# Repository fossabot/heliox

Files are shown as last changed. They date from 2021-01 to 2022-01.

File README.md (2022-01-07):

# Heliox





FOSSA Status (https://app.fossa.com/projects/git%2Bgithub.com%2FGHOSCHT%2Fheliox?ref=badge_shield)
<a href="https://www.figma.com/file/fK5tEIw4Zx8AivuVbu79Lw/Light-Control">
  
</a>

Uses: https://github.com/GHOSCHT/simple-electron-react-boilerplate

Dashboard: node-gyp fails on sqlite3 build -> set default pyhton version to python 2
```
node-gyp --python /path/to/python2.7/python.exe
```
or
```
npm config set python /path/to/executable/python2.7
```   

## License
FOSSA Status (https://app.fossa.com/projects/git%2Bgithub.com%2FGHOSCHT%2Fheliox?ref=badge_large)

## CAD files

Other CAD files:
Devices/Module/Hardware/Enclosure/Back Cover v18.f3z
Devices/Module/Hardware/Enclosure/Front Cover v3.f3d

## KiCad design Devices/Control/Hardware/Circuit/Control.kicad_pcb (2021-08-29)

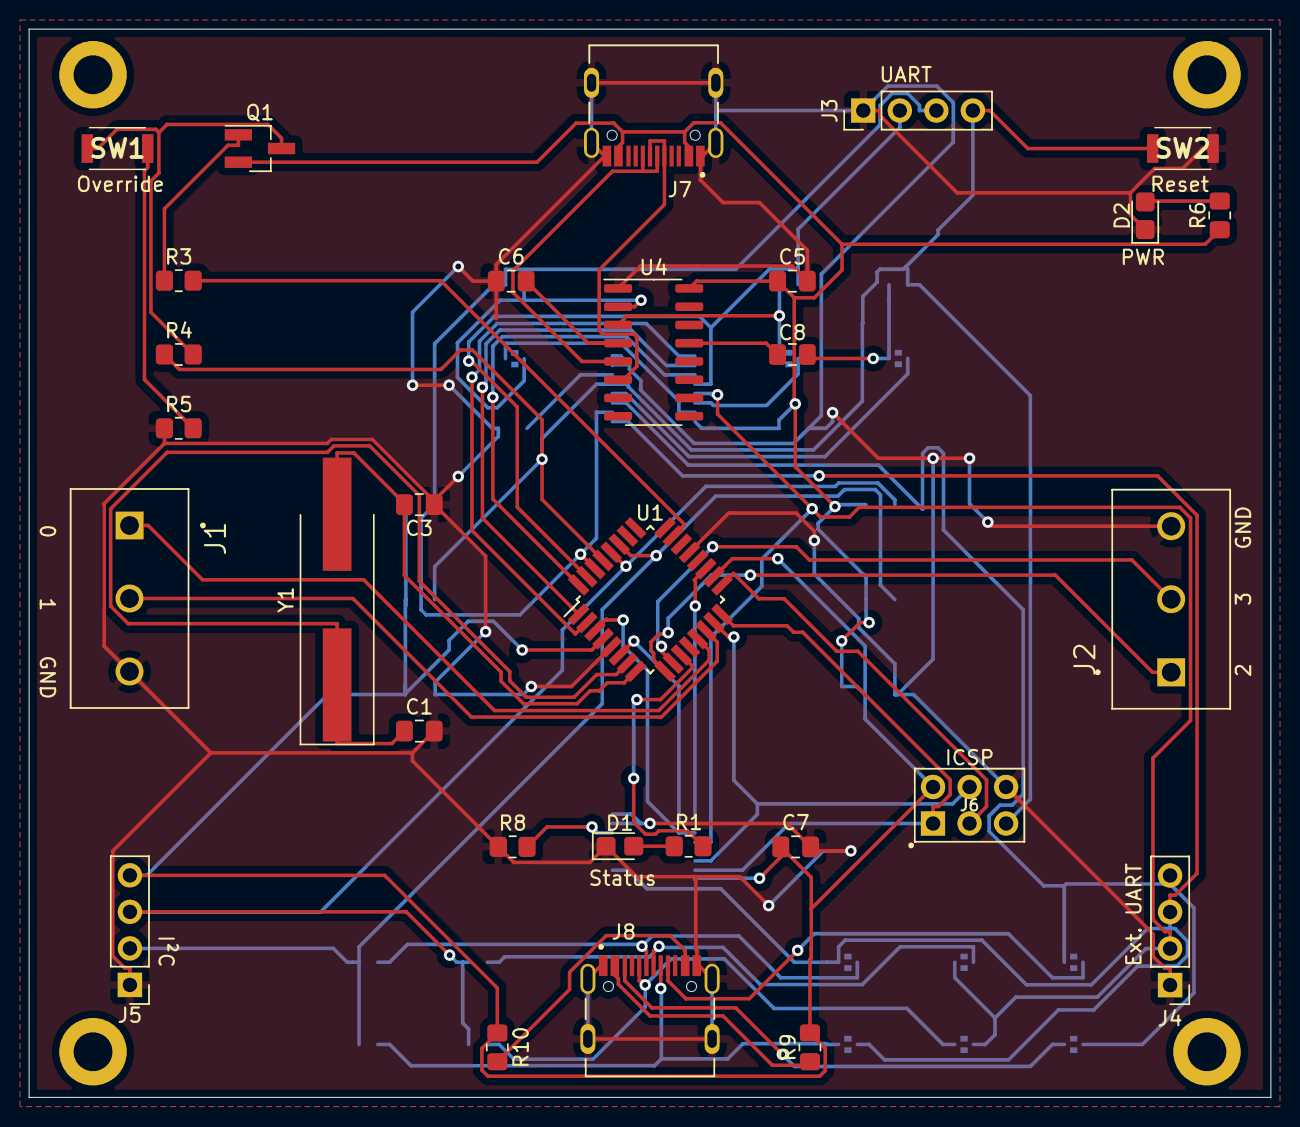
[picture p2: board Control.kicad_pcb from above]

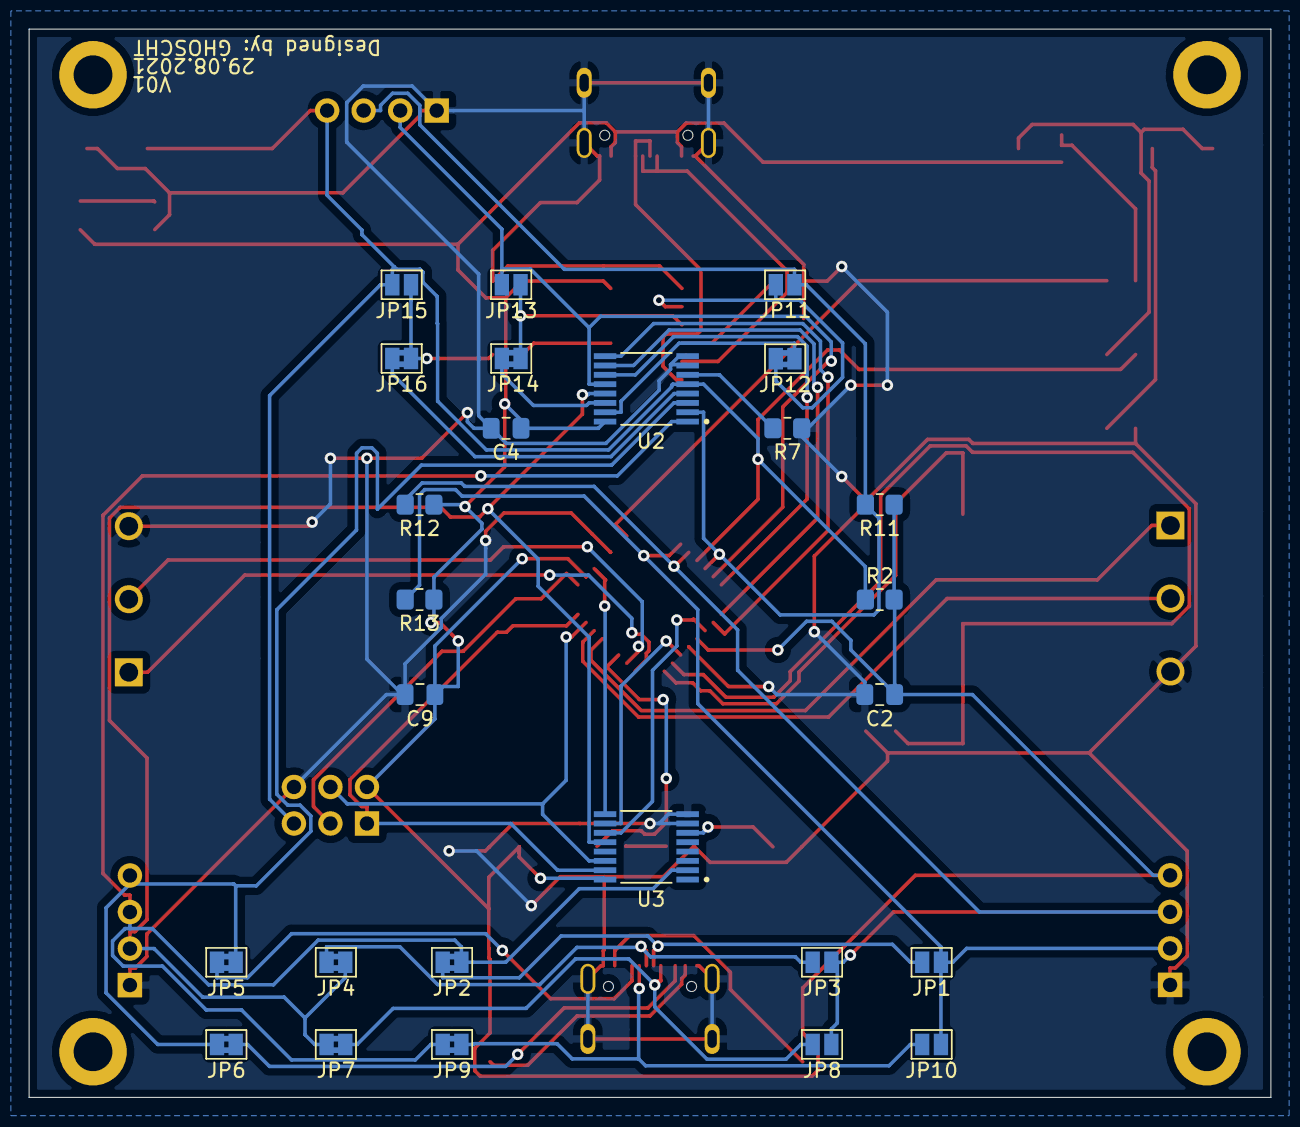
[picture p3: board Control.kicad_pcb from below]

Board: 2 copper layers, 86.4 x 74.3 mm, 60 parts (26 on the bottom side), 52 nets.

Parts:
C1, C3: 22p; C_0805_2012Metric_Pad1.18x1.45mm_HandSolder
C2, C4, C5, C6, C7, C8, C9: 100n; C_0805_2012Metric_Pad1.18x1.45mm_HandSolder
D1, D2: 17-21/BHC-XL2M2TY/3T; LED_0805_2012Metric_Castellated
J1, J2: Screw_Terminal_01x03; CUI_TB006-508-03BE
J3, J4, J5: Conn_01x04; PinHeader_1x04_P2.54mm_Vertical
J6: AVR-ISP-6; AVR-ISP
J7, J8: TYPE-C-31-M-12; HRO_TYPE-C-31-M-12
JP1, JP3, JP8, JP10, JP11, JP13, JP15: SolderJumper; SolderJumper-2_P1.3mm_Open_Pad1.0x1.5mm
JP2, JP4, JP5, JP6, JP7, JP9, JP12, JP14, JP16: SolderJumper_Bridged; SolderJumper-2_P1.3mm_Bridged2Bar_Pad1.0x1.5mm
MNT1, MNT2, MNT3, MNT4: MountingHole_2.7mm_M2.5_DIN965_Pad
Q1: Q_NPN_BCE; SOT-23_Handsoldering
R1, R6: 200; R_0805_2012Metric_Pad1.20x1.40mm_HandSolder
R2, R7, R8, R11, R12, R13: 10k; R_0805_2012Metric_Pad1.20x1.40mm_HandSolder
R3, R5, R9, R10: 40.2; R_0805_2012Metric_Pad1.20x1.40mm_HandSolder
R4: 120; R_0805_2012Metric_Pad1.20x1.40mm_HandSolder
SW1, SW2: SW_Push; SKRKAEE020
U1: ATmega328PB-AU; TQFP-32_7x7mm_P0.8mm
U2, U3: CD74HC4053PWR; SOP65P640X120-16N
U4: CH340C; SOIC-16_3.9x9.9mm_P1.27mm
Y1: 16MHz; Crystal_SMD_HC49-SD_HandSoldering

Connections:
D+: J7.A6, J7.B6, U4.5
D-: J7.A7, J7.B7, U4.6
EXTRST: J4.4, JP5.1, JP6.2, U2.3
EXTRX: J4.3, JP2.1, JP9.2, U2.1, U3.2
EXTTX: J4.2, JP4.1, JP7.2, U2.13, U3.12
GND: C1.2, C2.2, C3.2, C4.2, C5.2, C6.1, C7.2, C9.2, D1.1, D2.1, J1.3, J2.3, J3.1, J4.1, J5.1, J6.6, J7.A1B12, J7.B1A12, J7.S1, J7.S2, J7.S3, J7.S4, J8.A1B12, J8.B1A12, J8.S1, J8.S2, J8.S3, J8.S4, R5.1, R7.1, R8.1, SW2.2, U1.5, U1.21, U2.7, U2.8, U3.7, U3.8, U4.1
LED: R1.2, U1.11
MISO: J6.1, U1.16, U3.15
MOSI: J6.4, U1.15, U3.14
MUX1S0: U1.32, U2.11
MUX1S1: U1.1, U2.10
MUX1S2: U1.2, U2.9
MUX2S0: U1.3, U3.11
MUX2S1: U1.6, U3.10
MUX2S2: U1.19, U3.9
MUXRST: JP16.1, U2.4
MUXRX: JP12.1, U2.15
MUXTX: JP14.1, U2.14
unnamed: C6.2, U4.4
unnamed: C8.1, JP15.1, JP16.2
unnamed: C8.2, U4.13
unnamed: D1.2, R1.1
unnamed: D2.2, R6.1
unnamed: J8.A4B9, R9.2
unnamed: J8.A6, JP1.2, JP2.2
unnamed: J8.A7, JP3.2, JP4.2
unnamed: J8.A8, JP5.2
unnamed: J8.B4A9, R10.2
unnamed: J8.B6, JP9.1, JP10.2
unnamed: J8.B7, JP7.1, JP8.2
unnamed: J8.B8, JP6.1
unnamed: JP11.1, JP12.2, U4.2
unnamed: JP13.1, JP14.2, U4.3
unnamed: Q1.1, R3.1
unnamed: Q1.3, R4.2, SW1.1
unnamed: R5.2, SW1.2
unnamed: R7.2, U2.6
unnamed: R8.2, U3.6
RST: J3.4, J6.5, JP15.2, R2.1, R4.1, SW2.1, U1.29, U2.5
RX: J3.3, JP11.2, R11.2, U1.30, U2.2
SCK: J6.3, U1.17
SCL: J5.3, JP3.1, JP8.1, R12.2, U1.28
SDA: J5.2, JP1.1, JP10.1, R13.2, U1.27
SIG1A: J1.1, U1.13
SIG1B: J1.2, U1.14
SIG2A: J2.1, U1.9
SIG2B: J2.2, U1.10
STOPRST: R3.2, U1.23
TX: J3.2, JP13.2, U1.31, U2.12
VCC: C2.1, C4.1, C5.1, C7.1, C9.1, J5.4, J6.2, J7.A4B9, J7.B4A9, Q1.2, R2.2, R6.2, R9.1, R10.1, R11.1, R12.1, R13.1, U1.4, U1.18, U2.16, U3.16, U4.16
XTAL1: C1.1, U1.7, Y1.1
XTAL2: C3.1, U1.8, Y1.2

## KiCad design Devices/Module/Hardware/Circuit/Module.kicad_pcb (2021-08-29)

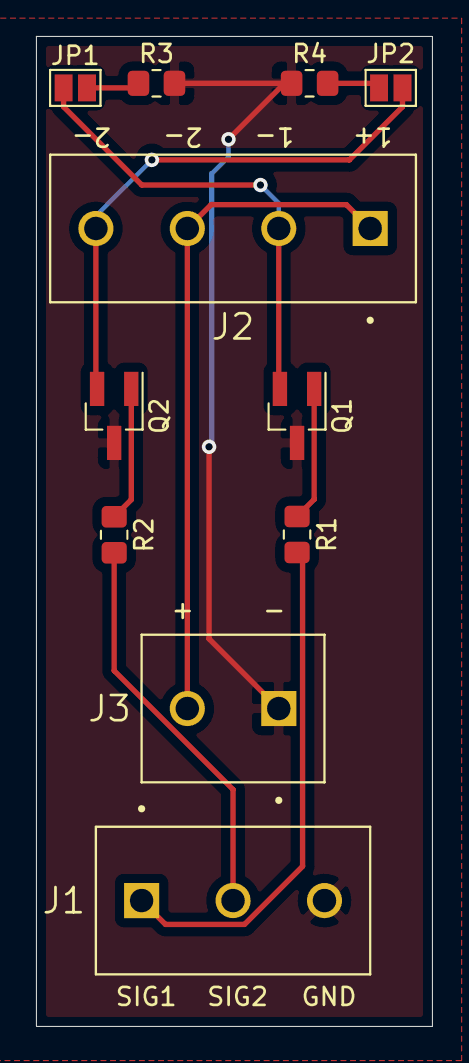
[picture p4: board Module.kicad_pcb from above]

Board: 2 copper layers, 22.0 x 55.0 mm, 11 parts (0 on the bottom side), 10 nets.

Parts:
J1: Screw_Terminal_01x03; CUI_TB006-508-03BE
J2: Screw_Terminal_01x04; CUI_TB006-508-04BE
J3: Screw_Terminal_01x02; CUI_TB006-508-02BE
JP1, JP2: Jumper; SolderJumper-2_P1.3mm_Open_Pad1.0x1.5mm
Q1, Q2: Q_NPN_BCE; SOT-23_Handsoldering
R1, R2: 470; R_0805_2012Metric_Pad1.20x1.40mm_HandSolder
R3, R4: 10k; R_0805_2012Metric_Pad1.20x1.40mm_HandSolder

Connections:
GND: J1.3, J3.1, Q1.3, Q2.3, R3.2, R4.1
LED1N: J2.2, JP1.1, Q1.2
LED2N: J2.4, JP2.1, Q2.2
unnamed: JP1.2, R3.1
unnamed: JP2.2, R4.2
unnamed: Q1.1, R1.1
unnamed: Q2.1, R2.1
SIG1: J1.1, R1.2
SIG2: J1.2, R2.2
VCC: J2.1, J2.3, J3.2

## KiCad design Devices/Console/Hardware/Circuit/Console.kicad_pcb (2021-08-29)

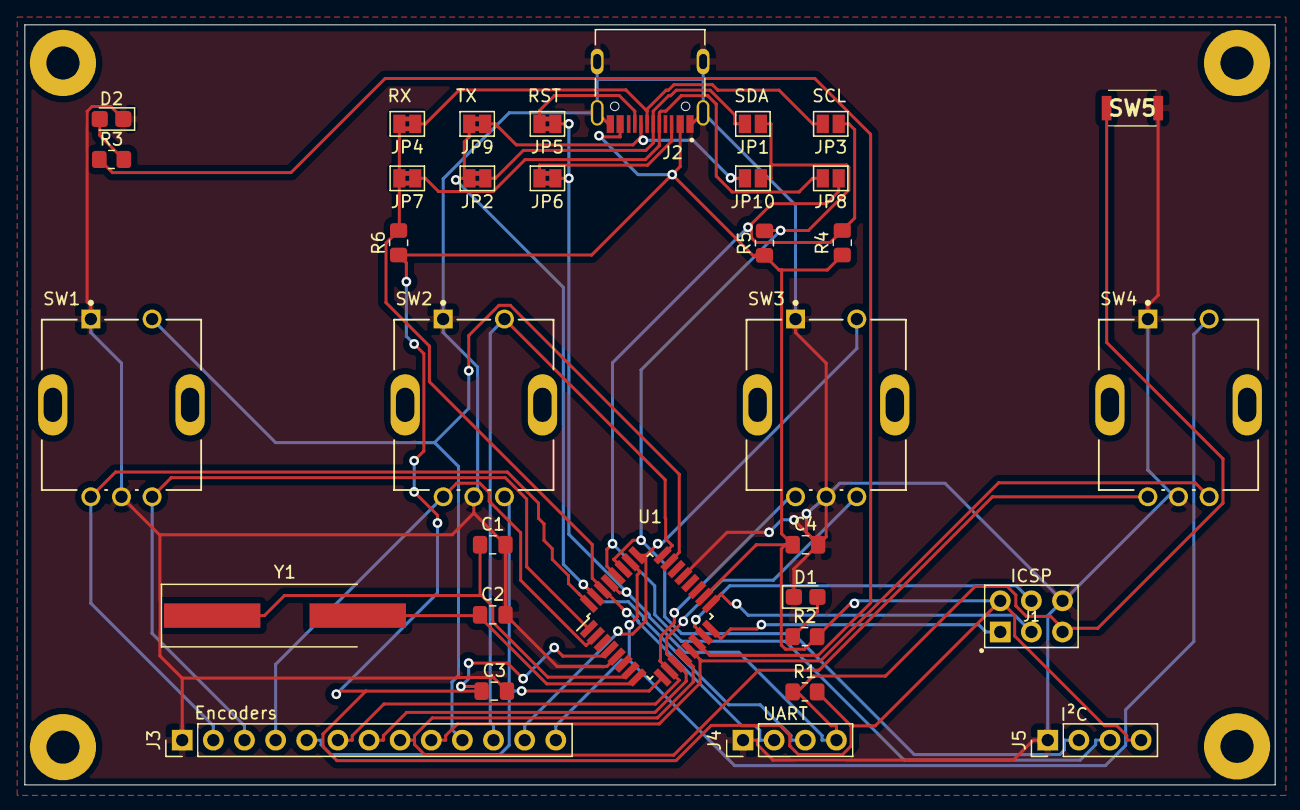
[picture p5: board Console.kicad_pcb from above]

Board: 2 copper layers, 102.0 x 62.0 mm, 38 parts (0 on the bottom side), 33 nets.

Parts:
C1, C2: 22p; C_0805_2012Metric_Pad1.18x1.45mm_HandSolder
C3, C4: 100n; C_0805_2012Metric_Pad1.18x1.45mm_HandSolder
D1, D2: 17-21/BHC-XL2M2TY/3T; LED_0805_2012Metric_Castellated
J1: AVR-ISP-6; AVR-ISP
J2: TYPE-C-31-M-12; HRO_TYPE-C-31-M-12
J3: Conn_01x13; PinHeader_1x13_P2.54mm_Vertical
J4, J5: Conn_01x04; PinHeader_1x04_P2.54mm_Vertical
JP1, JP3, JP8, JP10: SolderJumper; SolderJumper-2_P1.3mm_Open_Pad1.0x1.5mm
JP2, JP4, JP5, JP6, JP7, JP9: SolderJumper_Bridged; SolderJumper-2_P1.3mm_Bridged2Bar_Pad1.0x1.5mm
PAD1, PAD2, PAD3, PAD4: MountingHole_2.7mm_M2.5_Pad
R1, R4, R5, R6: 10k; R_0805_2012Metric_Pad1.20x1.40mm_HandSolder
R2, R3: 200; R_0805_2012Metric_Pad1.20x1.40mm_HandSolder
SW1, SW2, SW3, SW4: PEC11R-4220F-S0012; Bourns-PEC11R-4220F-S0012-MFG
SW5: SW_Push; SKRKAEE020
U1: ATmega328PB-AU; TQFP-32_7x7mm_P0.8mm
Y1: 16MHz; Crystal_SMD_HC49-SD_HandSoldering

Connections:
BTN1: J3.10, SW1.S2, U1.23
BTN2: J3.11, SW2.S2, U1.24
BTN3: J3.12, SW3.S2, U1.25
BTN4: J3.13, SW4.S2, U1.26
ENC1A: J3.2, SW1.A, U1.32
ENC1B: J3.3, SW1.B, U1.1
ENC2A: J3.4, SW2.A, U1.2
ENC2B: J3.5, SW2.B, U1.9
ENC3A: J3.6, SW3.A, U1.10
ENC3B: J3.7, SW3.B, U1.11
ENC4A: J3.8, SW4.A, U1.12
ENC4B: J3.9, SW4.B, U1.13
GND: C1.2, C2.2, C3.2, C4.2, D1.1, D2.1, J1.6, J2.A1B12, J2.B1A12, J2.S1, J2.S2, J2.S3, J2.S4, J3.1, J4.1, J5.1, SW1.C, SW1.S1, SW2.C, SW2.S1, SW3.C, SW3.S1, SW4.C, SW4.S1, SW5.2, U1.5, U1.21
LED: R3.2, U1.14
MISO: J1.1, U1.16
MOSI: J1.4, U1.15
unnamed: D1.2, R2.1
unnamed: D2.2, R3.1
unnamed: J2.A6, JP1.2, JP2.2
unnamed: J2.A7, JP3.2, JP4.2
unnamed: J2.A8, JP5.2
unnamed: J2.B6, JP9.1, JP10.1
unnamed: J2.B7, JP7.1, JP8.1
unnamed: J2.B8, JP6.1
RST: J1.5, J4.4, JP5.1, JP6.2, R1.1, SW5.1, U1.29
RX: J4.2, JP4.1, JP7.2, R6.2, U1.30
SCK: J1.3, U1.17
SCL: J5.3, JP3.1, JP8.2, R4.2, U1.28
SDA: J5.2, JP1.1, JP10.2, R5.2, U1.27
TX: J4.3, JP2.1, JP9.2, U1.31
VCC: C3.1, C4.1, J1.2, J2.A4B9, J2.B4A9, J5.4, R1.2, R2.2, R4.1, R5.1, R6.1, U1.4, U1.18
XTAL1: C1.1, U1.7, Y1.1
XTAL2: C2.1, U1.8, Y1.2

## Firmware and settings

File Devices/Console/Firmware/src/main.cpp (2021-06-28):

#include <Arduino.h>
#include <Wire.h>

//General
const int bjtCount = 4;
const int btnPin[bjtCount] = {7, 8, 9, 10};

byte btnState[bjtCount];
byte lastBtnState[bjtCount] = {HIGH, HIGH, HIGH, HIGH};

unsigned long lastDebounceTime[bjtCount] = {0, 0, 0, 0};
unsigned long debounceDelay = 50;

//I2C
const int SLAVE_ADDR = 9;

//Rotary Encoder
const int encClkPin[1] = {6};
const int encDtPin[1] = {5};

void setup()
{
    Serial.begin(9600);
    Wire.begin();

    for (int i = 0; i < bjtCount; i++)
    {
        pinMode(btnPin[i], INPUT_PULLUP);
        pinMode(encClkPin[i], INPUT_PULLUP);
        pinMode(encDtPin[i], INPUT_PULLUP);
    }
}

void transmit(String data)
{
    Wire.beginTransmission(SLAVE_ADDR);
    Wire.write(data.c_str(), 2);
    Serial.println(data.c_str());
    Wire.endTransmission();
}

void loop()
{
    //Buttons
    byte btnReading[bjtCount];

    for (int i = 0; i < bjtCount; i++)
    {
        btnReading[i] = digitalRead(btnPin[i]);

        if (btnReading[i] != lastBtnState[i])
        {
            lastDebounceTime[i] = millis();
        }

        if ((millis() - lastDebounceTime[i]) > debounceDelay)
        {
            if (btnReading[i] != btnState[i])
            {
                btnState[i] = btnReading[i];

                if (btnState[i] == LOW)
                {
                    transmit(String(i) + "t");
                }
            }
        }

        lastBtnState[i] = btnReading[i];
    }

    //Rotary Encoder
    static uint16_t state[1] = {0};

    //delayMicroseconds(100); // Simulate doing somehing else as well.

    for (int i = 0; i < 1; i++)
    {
        state[i] = (state[i] << 1) | digitalRead(encClkPin[i]) | 0xe000;

        if (state[i] == 0xf000)
        {
            state[i] = 0x0000;
            if (digitalRead(encDtPin[i]))
                //transmit(String(i) + "i");
                transmit("2i");
            else
                //transmit(String(i) + "d");
                transmit("2d");
        }
    }
}

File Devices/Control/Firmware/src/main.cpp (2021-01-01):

#include <Arduino.h>
#include <EEPROM.h>
#include <Wire.h>

#define SLAVE_ADDR 9
const int bjtCount = 4;

const int bjtPin[bjtCount] = {6, 5, 3, 10};
int bjtState[bjtCount] = {255, 255, 255, 255}; //255 -> bjt max "open"

char receivedSerialData[4];
char receivedI2cData[4];
String pendingSerialData;

void changeLights(char data[])
{
  for (int i = 0; i < bjtCount; i++)
  {
    char numChar[2];
    itoa(i, numChar, 10);

    if (data[0] == numChar[0])
    {
      if (data[1] == 't')
      {
        if (bjtState[i] != 0)
        {
          bjtState[i] = 0;
        }
        else
        {
          bjtState[i] = 255;
        }
      }
      else if (data[1] == 'i')
      {
        bjtState[i] += 5;
      }
      else if (data[1] == 'd')
      {
        bjtState[i] -= 5;
      }
    }

    //clamp state between 0 and 255
    if (bjtState[i] > 255)
    {
      bjtState[i] = 255;
    }

    if (bjtState[i] < 0)
    {
      bjtState[i] = 0;
    }

    //set absolute state for all
    if (!strcmp(data, "off"))
    {
      bjtState[i] = 0;
    }

    if (!strcmp(data, "on"))
    {
      bjtState[i] = 255;
    }

    analogWrite(bjtPin[i], bjtState[i]);
    EEPROM.update(i, bjtState[i]);
  }

  memset(data, ' ', 3);
}

void receiveEvent(int byteCount)
{
  char buffer[byteCount];
  for (int i = 0; i < byteCount; i++)
  {
    buffer[i] = Wire.read();
  }
  memset(receivedI2cData, ' ', 3);
  strcpy(receivedI2cData, buffer);
}

void setup()
{
  Serial.begin(9600);
  Serial.setTimeout(5);
  Wire.begin(SLAVE_ADDR);
  Wire.onReceive(receiveEvent);

  for (int i = 0; i < bjtCount; i++)
  {
    pinMode(bjtPin[i], OUTPUT);
    bjtState[i] = EEPROM.read(i);
    analogWrite(bjtPin[i], bjtState[i]);
  }
}

void loop()
{
  while (Serial.available())
  {
    strcpy(receivedSerialData, Serial.readString().c_str());
  }

  changeLights(receivedSerialData);
  changeLights(receivedI2cData);

  pendingSerialData = "";
  for (int i = 0; i < bjtCount; i++)
  {
    noInterrupts();
    pendingSerialData += String(bjtState[i]) + ",";
    interrupts();
  }
  pendingSerialData.remove(pendingSerialData.length() - 1);
  Serial.println(pendingSerialData);
}

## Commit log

2020-07-30 Switch electron boilerplates
2020-07-30 Add on & off commands + Relay state communication
2020-08-01 Add material ui
2020-08-01 Add Buttons
2020-08-01 Remove unnecessary props
2020-08-02 Arduino builder error test
2020-08-02 Revert "Arduino builder error test"
    This reverts commit 97cf7e37e65544a997c7bfe0c96db386e0ee02a5.
2020-12-18 Switch to PWM instead of Digital bjt control
2020-12-19 Implement PWM dimming via COM
2020-12-27 Implemented button sending over i2c
2020-12-27 kind of responds to i2c button press
2021-01-01 Add one rotary encoder
2021-03-27 Add Button Debouncing
2021-06-28 Add support for multiple encoders
2021-06-30 Add precommit lint-staged
2021-08-05 File restructuring
    [Console.kicad_pcb, Console.sch, Control.kicad_pcb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]
2021-08-10 Add KiCad gitignore
2021-08-10 Rough console part selection
    [Console.kicad_pcb, Console.sch]
2021-08-10 Exchange Micro USB with Type C
    [Console.kicad_pcb, Console.sch]
2021-08-10 First rough console schematic
    [Console.kicad_pcb, Console.sch]
2021-08-10 Add encoder breakout connector
    [Console.sch]
2021-08-10 Add communication breakout pins
    [Console.kicad_pcb, Console.sch]
2021-08-10 Add schematic annotations
    [Console.sch]
2021-08-11 Add led power indicator
    [Console.sch]
2021-08-11 Change net label type to global
    [Console.kicad_pcb, Console.sch]
2021-08-11 Add ERC power flag
    [Console.sch]
2021-08-13 Add basic component selection to control
    [Control.kicad_pcb, Control.sch]
2021-08-13 Make serial solder jumper bridged
    [Console.sch]
2021-08-13 Add first USB to serial functionality
    [Control.sch]
2021-08-15 Add uart multiplexer
    [Control.kicad_pcb, Control.sch]
2021-08-15 Add console UART muxing
    [Control.kicad_pcb, Control.sch]
2021-08-15 Add control reset functionality
    [Control.kicad_pcb, Control.sch]
2021-08-15 Add reset button to console
    [Console.sch]
2021-08-15 Change console reset button symbol + solder jumper footprint
    [Console.kicad_pcb, Console.sch]
2021-08-15 Add external reset sensing to control
    [Control.sch]
2021-08-16 Add Hardware Serial connections
    [Control.sch]
2021-08-16 Add first rough connections of atmega328pb
    [Control.sch]
2021-08-17 Restructure control schematic
    [Control.kicad_pcb, Control.sch]
2021-08-17 Add status led to control
    [Control.kicad_pcb, Control.sch]
2021-08-17 Add PB processor & status led to console
    [Console.kicad_pcb, Console.sch]
2021-08-17 Add module circuit files
    [Module.kicad_pcb, Module.sch]
2021-08-17 Add module enclosure files
    [Back Cover v18.f3z, Front Cover v3.f3d]
2021-08-17 Add 1x06 screw terminal files to control
2021-08-17 Add module circuit
    [Module.kicad_pcb, Module.sch]
2021-08-19 Add input serial mux & Change pin header footprint
    [Control.kicad_pcb, Control.sch]
2021-08-19 Change pin header size
    [Console.kicad_pcb, Console.sch]
2021-08-19 Change through-hole size
    [Control.kicad_pcb]
2021-08-19 Finish module PCB layout
    [Module.kicad_pcb, Module.sch]
2021-08-19 First console PCB layout
    [Console.kicad_pcb]
2021-08-19 Change ISP footprint to through-hole
    [Console.kicad_pcb]
2021-08-19 Relocate ISP header
    [Console.kicad_pcb]
2021-08-19 Flip components for easier wiring
    [Console.kicad_pcb]
2021-08-19 Add second more centered pcb layout
    [Console-v1.kicad_pcb]
2021-08-19 Finalize PCB
    [Console.kicad_pcb]
2021-08-19 Add breakout pin description
    [Console.kicad_pcb]
2021-08-19 Add proper mounting holes
    [Console.kicad_pcb]
2021-08-19 Improve routing with freerouting + manual fixes
    [Console.dsn, Console.kicad_pcb]
2021-08-19 Add additional decoupling capacitor
    [Console.kicad_pcb, Console.sch]
2021-08-19 Secondary decoupling capacitor traces
    [Console-v2.kicad_pcb, Console.dsn]
2021-08-19 Switch LED location
    [Console-v2.kicad_pcb, Console.dsn, Console.kicad_pcb]
2021-08-19 Add pulldown resistor
    [Module.kicad_pcb, Module.sch]
2021-08-23 Change pulldown track width
    [Module.kicad_pcb]
2021-08-23 Bigger spacing between encoders
    [Console.dsn, Console.kicad_pcb]
2021-08-23 Wider encoder gap pcb traces
    [Console.kicad_pcb]
2021-08-23 Plot Gerber files
    [Console-B_Cu.gbr, Console-B_Mask.gbr, Console-B_Paste.gbr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]
2021-08-23 Switch to Minicore bootloader
2021-08-23 Switch console to Minicore
2021-08-24 Switch to Minicore & enable reset toggle on upload
2021-08-24 Add UART upload forwarding
2021-08-25 Generate Gerbers
    [Console-B_Cu.gbl, Console-B_Cu.gbr, Console-B_Mask.gbr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]
2021-08-25 Add reset hardware override
    [Control.kicad_pcb, Control.sch]
2021-08-26 Revert "Buffer boundary check - test 1"
    This reverts commit 1c0c7449838e07e96a0cbd041e050235f85f8ebe.
    [main.cpp]
2021-08-26 Remove Gerber folder
    [Console-B_Cu.gbl, Console-B_Mask.gbs, Console-B_Paste.gbp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]
2021-08-26 Exclude Gerber folder from sync
2021-08-27 Switch from abandonned remote-dev-server to @redux-devtools/cli
2021-08-27 Pin dependencies
2021-08-29 Add UART/I2C pull-up resistors
    [Console.dsn, Console.kicad_pcb, Console.sch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]
2021-08-29 Add port names on silkscreen
    [Module.kicad_pcb]
2021-08-29 First control PCB
    [Control.dsn, Control.kicad_pcb, Control.sch]
2021-08-29 Add mounting holes & component description
    [Control.kicad_pcb, Control.sch]
2021-08-29 Add version number & author information
    [Control.kicad_pcb]
2021-08-29 Fix output port numbering
    [Control.kicad_pcb]
2021-12-31 First switch to redux-toolkit
2021-12-31 Switch to integrated redux devtools
2021-12-31 Comment out currently unused code
2021-12-31 Hook up disconnect to UI button
